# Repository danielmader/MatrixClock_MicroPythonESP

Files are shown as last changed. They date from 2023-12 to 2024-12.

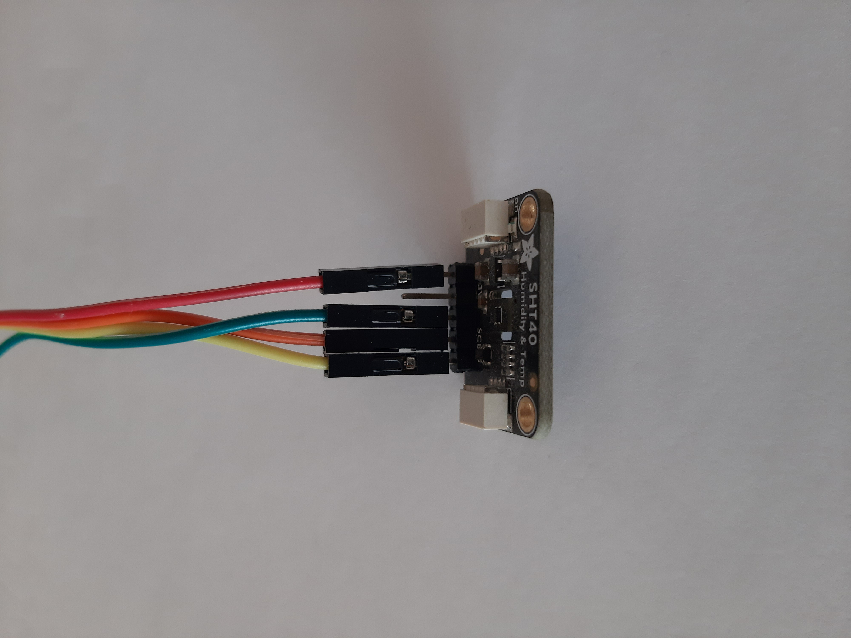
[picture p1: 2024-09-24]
20240922_105024.jpg

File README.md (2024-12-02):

# MatrixClock_MicropythonESP
A simple clock for a 64x32 HUB75 LED matrix display with scheduled NTP sync and Sensirion SHT40 ambient sensor.

# Setup

## RGB LED matrix 64x32
The display (23,95€) is from WaveShare (and was much cheaper than the similar product from Adafruit):
- https://www.waveshare.com/wiki/RGB-Matrix-P4-64x32
- https://eckstein-shop.de/WaveShare-RGB-Full-Color-LED-Matrix-Panel-64x32-Pixels-4mm-Pitch-Adjustable-Brightness

Here I've found very valuable information about how to use this kind of display:
- https://www.bigmessowires.com/2018/05/24/64-x-32-led-matrix-programming/
- https://www.sparkfun.com/news/2650

## Power supply
Interestingly enough, the display can be used without power supply, i.e. the small current fed into the HUB75 connector is enough to have the red pixels light up dimly, which is perfect for my use case as a night clock. During daytime, I'll turn on the 5V DC supply using a relay (yet to be implemented).

I'm using a salvaged 12V 1.5A power supply for the HUB75 controller. The required 5V are generated by this handy little DC-DC step-down converter (3.50€) with 10W output (15W max):
- https://eckstein-shop.de/LM2596SDC-DCeinstellbarerStep-DownSpannungsreglermitLED-VoltmeterAdjustablePowerModul

## I²C temperature and pressure sensor
The sensor (7.95€) came on a convenient break-out board from Adafruit:
- https://learn.adafruit.com/adafruit-sht40-temperature-humidity-sensor
- https://eckstein-shop.de/AdafruitSensirionSHT40Temperature26HumiditySensor-STEMMAQT2FQwiic

# Dependencies

This project requires [Ben Emmett's Hub75MicroPython](https://github.com/benjohnemmett/Hub75MicroPython) library, which is perfectly suitable for a simple MicroPython-only application. Ben was very helpful to optimize his library to maximum performance and provided numerous tips and tricks on how to implement it.

There is still a noticable flicker when the screen objects are changed (and also sporadically when the board is busy), but it is certainly acceptable for an update of the clockface every minute.

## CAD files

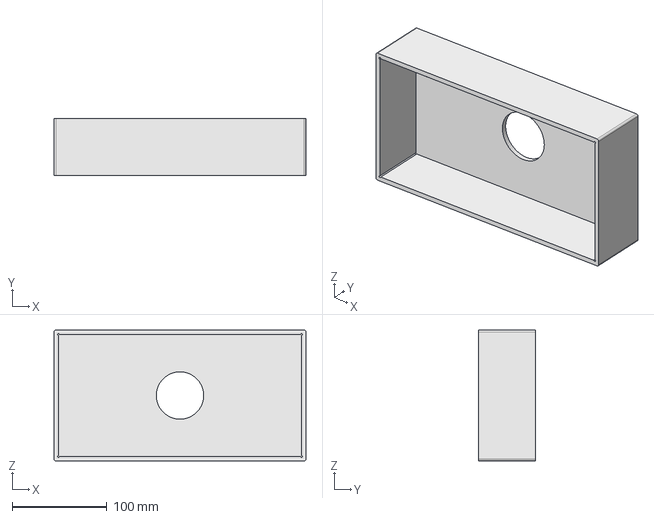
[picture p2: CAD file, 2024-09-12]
CAD/Housing v1.0.FCStd
266.0 x 60.0 x 138.0 mm

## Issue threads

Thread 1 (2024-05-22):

How to display string content?

mrhanCH, 2024-05-22:
Hello, great job. I noticed in your presentation that the red time doesn't seem very clear. Is it due to insufficient brightness? Or is it due to camera shooting?
Also, may I ask if you have a suitable method for displaying English words or Chinese characters?
Thank you!

danielmader, 2024-05-26:
Thanks for your comment!
There is no way to write letters directly with the low level approach of my project.
Maybe the Hub75 library of Circuit Python can help you.
Best luck!

Closed 2024-05-26.

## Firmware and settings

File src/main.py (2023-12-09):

# -*- coding: utf-8 -*-

"""
MatrixClock - an ESP32 driven HUB75 LED matrix clock.
* Synchronization with NTP.
* Temperature/humidity ambient sensor (Sensirion SHT40).

@author: mada
@version: 2023-12-09
"""

## System modules
from machine import Timer
from machine import Pin
from machine import I2C

import ntptime

import uasyncio as asyncio
import utime as time

## 3rd party modules
import hub75
import matrixdata
from logo import logo

## Custom modules
import wlan_util  # => creds.py
import datetime_util
import characters

##*****************************************************************************
##*****************************************************************************

## DEBUG mode -----------------------------------------------------------------
debug_mode = False
# debug_mode = True

## NTP sync interval ----------------------------------------------------------
ntp_interval = 3600 * 12  # 3600s = 60min = 1h
ts_ntpsync = 0

## Init clock -----------------------------------------------------------------
if debug_mode:
    ## Start at 05:59:00 UTC = 06:59:00 CET ...
    ts_clocktick = 60 * 60 * 5 + 59 * 60
else:
    ## Start at 00:00:00 UTC
    ts_clocktick = time.time()

## HUB75 LED matrix with custom pinout ----------------------------------------
config = hub75.Hub75SpiConfiguration()
## Row select pins
config.line_select_a_pin_number = 15
config.line_select_b_pin_number = 2
config.line_select_c_pin_number = 4
config.line_select_d_pin_number = 16
config.line_select_e_pin_number = 12
## Color data pins
config.red1_pin_number = 32
config.green1_pin_number = 33
config.blue1_pin_number = 25
config.red2_pin_number = 26
config.green2_pin_number = 27
config.blue2_pin_number = 14
## Logic pins
config.clock_pin_number = 18
config.latch_pin_number = 5
config.output_enable_pin_number = 17  # active low
config.spi_miso_pin_number = 13  # not connected
## Misc
# config.illumination_time_microseconds = 1

matrix = matrixdata.MatrixData(row_size=32, col_size=64)
matrix.record_dirty_bytes = True

hub75spi = hub75.Hub75Spi(matrix, config)

## Dot matrix characters ------------------------------------------------------
## Characters are 2D arrays with 0..7 for 3-bit colors RGB
## Blue is #001b, i.e. 1
big_blue = {
    '0' : characters.big0,         # 8 x14
    '1' : characters.big1,         # 8 x14
    '2' : characters.big2,         # 8 x14
    '3' : characters.big3,         # 8 x14
    '4' : characters.big4,         # 8 x14
    '5' : characters.big5,         # 8 x14
    '6' : characters.big6,         # 8 x14
    '7' : characters.big7,         # 8 x14
    '8' : characters.big8,         # 8 x14
    '9' : characters.big9,         # 8 x14
    '.' : characters.big_dot,      # 2 x14
    ':' : characters.big_colon,    # 2 x14
    '°' : characters.big_degree,   # 4 x14
    'C' : characters.big_degreeC,  # 8 x14
    '%' : characters.big_percent,  # 8 x14
    '-' : characters.big_dash,     # 8 x14
    ' ' : characters.big_space,    # 8 x14
    '~' : characters.pixel_black,  # 1 x1
    }

small_blue = {
    '0' : characters.small0,         # 5 x7
    '1' : characters.small1,         # 5 x7
    '2' : characters.small2,         # 5 x7
    '3' : characters.small3,         # 5 x7
    '4' : characters.small4,         # 5 x7
    '5' : characters.small5,         # 5 x7
    '6' : characters.small6,         # 5 x7
    '7' : characters.small7,         # 5 x7
    '8' : characters.small8,         # 5 x7
    '9' : characters.small9,         # 5 x7
    '.' : characters.small_dot,      # 1 x7
    ':' : characters.small_colon,    # 1 x7
    '°' : characters.small_degree,   # 3 x7
    'C' : characters.small_degreeC,  # 6 x7
    '%' : characters.small_percent,  # 5 x7
    '-' : characters.small_dash,     # 4 x7
    ' ' : characters.small_space,    # 5 x7
    '~' : characters.pixel_black,    # 1 x1
    }

## Yellow is #110b, i.e. 6
big_yellow = {}
for char in big_blue:
    big_yellow[char] = []
    for i, row in enumerate(big_blue[char]):
        row = [col * 6 for col in row]  # yellow
        big_yellow[char].append(row)
small_yellow = {}
for char in small_blue:
    small_yellow[char] = []
    for i, row in enumerate(small_blue[char]):
        row = [col * 6 for col in row]  # yellow
        small_yellow[char].append(row)

## SHT40 temperature & pressure sensor ----------------------------------------
modes = (
    ("SERIAL_NUMBER", 0x89, "Serial number", 0.01),
    ("NOHEAT_HIGHPRECISION", 0xFD, "No heater, high precision", 0.01),
    ("NOHEAT_MEDPRECISION", 0xF6, "No heater, med precision", 0.005),
    ("NOHEAT_LOWPRECISION", 0xE0, "No heater, low precision", 0.002),
    ("HIGHHEAT_1S", 0x39, "High heat, 1 second", 1.1),
    ("HIGHHEAT_100MS", 0x32, "High heat, 0.1 second", 0.11),
    ("MEDHEAT_1S", 0x2F, "Med heat, 1 second", 1.1),
    ("MEDHEAT_100MS", 0x24, "Med heat, 0.1 second", 0.11),
    ("LOWHEAT_1S", 0x1E, "Low heat, 1 second", 1.1),
    ("LOWHEAT_100MS", 0x15, "Low heat, 0.1 second", 0.11),
    )
i2c = I2C(0, scl=Pin(22), sda=Pin(21))
i2c_devs = i2c.scan()
print("\n>> found I2C devices:", i2c_devs)
sht40 = i2c_devs[0]

##*****************************************************************************
##*****************************************************************************


##=============================================================================
def read_sensor():
    '''
    Read measurement data from Sensirion SHT40.

    Returns
    -------
    * t_degC : float
    * rh_pRH : float
    '''
    # print ("\n>> reading sensor data ...")
    mode =  modes[1]  # NOHEAT_HIGHPRECISION
    i2c.writeto(sht40, bytearray([mode[1]]))
    time.sleep(mode[-1])
    rx_bytes = i2c.readfrom(sht40, 6)
    # print('>', rx_bytes, len(rx_bytes))
    t_ticks = rx_bytes[0] * 256 + rx_bytes[1]
    rh_ticks = rx_bytes[3] * 256 + rx_bytes[4]
    t_degC = -45 + 175 * t_ticks / 65535  # 2^16 - 1 = 65535
    rh_pRH = -6 + 125 * rh_ticks / 65535
    if (rh_pRH > 100):
        rh_pRH = 100
    if (rh_pRH < 0):
        rh_pRH = 0
    # print('> temperature:', t_degC)
    # print('> humidity:', rh_pRH)
    return t_degC, rh_pRH


##=============================================================================
def set_clock(timestamp=None):
    '''
    Update the display readings.
    '''
    ##-------------------------------------------------------------------------
    ## Assemble raw time and sensor strings
    if not timestamp:
        timestamp = ts_clocktick

    localtime = datetime_util.cettime(timestamp)
    # if len(localtime) == 8:
    #     ## MicroPython
    #     year, month, mday, hour, minute, second, weekday, yearday = localtime
    # elif len(localtime) == 9:
    #     ## CPython
    #     year, month, mday, hour, minute, second, weekday, yearday, dst = localtime
    hour, minute, second = localtime[3:6]
    try:
        temp, hum = read_sensor()
    except Exception:
        temp, hum = None, None

    ## DEBUG
    # if second // 10 == 0:
    #     temp, hum = 9.9, 55.5
    # elif second // 10 == 1:
    #     temp, hum = -9.9, 55.5
    # elif second // 10 == 2:
    #     temp, hum = -11.1, 55.5
    # elif second // 10 == 3:
    #     temp, hum = 3.3, 4.4
    # elif second // 10 == 4:
    #     temp, hum = 22.2, 55.5
    # elif second // 10 == 5:
    #     temp, hum = None, None

    time_str = "{:02d}:{:02d}.{:02d}".format(hour, minute, second)
    try:
        sensor_str = "{:4.1f}C {:4.1f}%".format(temp, hum)
    except ValueError:
        sensor_str = '----  ----'
    print("{} / {}".format(time_str, sensor_str))

    ##-------------------------------------------------------------------------
    ## Use darkmode during night time
    ## TODO: handle darkmode
    # if hour in [20,21,22,23,0,1,2,3,4,5,6]:
    #     darkmode = True
    # else:
    #     darkmode = False
    big = big_yellow
    small = small_yellow

    ##-------------------------------------------------------------------------
    ## Assemble character images lists per line
    time_display = []
    sensor_display = []
    ## Time HH:MM in big chars
    for char in time_str[:-3]:
        time_display.append(big[char])
    ## Time .SS in small chars
    for char in time_str[-3:]:
        time_display.append(small[char])
    ## Sensor data in small chars
    for char in sensor_str:
        sensor_display.append(small[char])

    ##-------------------------------------------------------------------------
    ## Concatenate character arrays and center on screen
    matrix.clear_dirty_bytes()
    # matrix.clear_all_bytes()

    ## Default character spacings
    space_big = 2    # default spacing for 'big'
    space_small = 1  # default spacing for 'small'

    ## 1) pixels(HH:MM)    = 2*8(+4) + 2(+2) + 2*8(+2) = 42
    ## 2) pixels(HH:MM.SS) = 42(+2) + 1+2*5(+2)        = 57
    # => 1st column index is ((64 - pixels) / 2) =
    ## 1) : 11
    ## 2) :  3.5
    ## TODO: Show full timestamp when flickerfree, see async def _set_clock()
    col = 4   # HH:MM.ss
    col = 11  # HH:MM
    for img in time_display[:-3]:
        matrix.set_pixels(5, col, img)
        col += len(img[0]) + space_big
    # for img in time_display[-3:]:
    #     matrix.set_pixels(5, col, img)
    #     col += len(img[0]) + space_small

    ## 1) pixels('xx.xC xx.x%') = 5+5+1+5+6(+5) + [5](+1) + 5+5+1+5+5(+4) = 58
    ## 2) pixels('-x.xC xx.x%') = 4+5+1+5+6(+5) + [5](+1) + 5+5+1+5+5(+4) = 57
    ## 3) pixels('-xx.xC xx.x%') = 4(+1) + 58                             = 63
    ## 4) pixels('----  ----') = 8*4 + 2*5 (+9)                           = 51
    ## => 1st column index is ((64 - pixels) / 2) =
    ## 1) :  3
    ## 2) :  3.5
    ## 3) :  0.5
    ## 4) :  6.5
    if len(sensor_str) == 11 and temp >= 0:
        col = 3
    if len(sensor_str) == 11 and temp < 0:
        col = 4
    elif len(sensor_str) == 12:
        col = 1
    elif len(sensor_str) == 10:
        col = 7
    for img in sensor_display:
        matrix.set_pixels(22, col, img)
        col += len(img[0]) + space_small


##-----------------------------------------------------------------------------
async def _set_clock(lock):
    '''
    Scheduler to update the display readings.
    '''
    while True:
        print("{:02d}.{:02d}:{:02d}".format(*time.localtime(ts_clocktick)[3:6]))

        ## TODO: update every second when when flickerfree
        # if ts_clocktick % 30 == 0:  # 2023-06-30: update every 30secs
        if ts_clocktick % 10 == 0:  # 2023-12-06: update every 10secs
            await lock.acquire()
            set_clock()
            lock.release()
        await asyncio.sleep(1)


##=============================================================================
def sync_time_NTP():
    '''
    Synchronize via NTP.
    '''
    try:
        print('\n>> syncing with NTP ...')
        ## check connection status, and (re-)connect if required
        wlan_util.connect()

        ## get time
        # print('<< NTP timestamp:', ntptime.time())
        ## set time
        ntptime.settime()
        print('<< NTP timestamp:', time.time())
        return True

    except Exception:
        print('!! NTP synchronization failed!')
        return False


##-----------------------------------------------------------------------------
async def _sync_time_NTP(lock):
    '''
    Scheduler to synchronize via NTP.
    '''
    global ts_clocktick
    global ts_ntpsync

    while True:
        if (ts_ntpsync == 0) or (ts_clocktick - ts_ntpsync > ntp_interval):
            await lock.acquire()
            for _ in range(5):
                if sync_time_NTP():
                    ts_clocktick = time.time()
                    ts_ntpsync = ts_clocktick
                    #print(datetime_util.cettime(ts_clocktick))

                    ## update clock immediately after NTP sync
                    set_clock()
                    break
            lock.release()

        await asyncio.sleep(5)


##-----------------------------------------------------------------------------
async def _refresh_display(lock):
    '''
    Scheduler to show/refresh the display.
    '''
    while True:
        await lock.acquire()
        hub75spi.display_data()
        lock.release()
        await asyncio.sleep(0)


##-----------------------------------------------------------------------------
def _clocktick(timer):
    '''
    Timed function to add one second.
    '''
    global ts_clocktick

    ts_clocktick += 1


##=============================================================================
async def main():
    ##-------------------------------------------------------------------------
    ## show Python Logo
    matrix.set_pixels(0, 16, logo)
    for _ in range(100):
        hub75spi.display_data()

    ##-------------------------------------------------------------------------
    ## init WiFi
    wlan_util.init()

    ##-------------------------------------------------------------------------
    ## init timer
    ## https://docs.micropython.org/en/latest/esp8266/quickref.html#timers
    ## https://docs.micropython.org/en/latest/esp32/quickref.html#timers
    tim = Timer(0)
    if not debug_mode:
        period = 1000
    else:
        ## run 5x faster
        period = 200
    tim.init(period=period, mode=Timer.PERIODIC, callback=_clocktick)

    ##-------------------------------------------------------------------------
    ## create the Lock instance
    lock = asyncio.Lock()

    ##-------------------------------------------------------------------------
    ## create co-routines (cooperative tasks)
    asyncio.create_task(_set_clock(lock))
    asyncio.create_task(_refresh_display(lock))
    asyncio.create_task(_sync_time_NTP(lock))

    while True:
        await asyncio.sleep(0)

try:
    asyncio.run(main())
finally:
    ## clear retained state
    _ = asyncio.new_event_loop()

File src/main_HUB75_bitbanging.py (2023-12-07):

# -*- coding: utf-8 -*-

"""
Minimum example for basic control of a HUB75 LED matrix (WaveShare 64x32) w/ NodeMCU ESP32.

@author: mada
@version: 2023-02-13
"""

## system modules
import time
#from machine import I2C
from machine import Pin

##*****************************************************************************
##*****************************************************************************

print(">>>> Setting pin definitions for HUB75 connector ...")
# R1 = Pin(25, Pin.OUT)
# G1 = Pin(26, Pin.OUT)
# B1 = Pin(27, Pin.OUT)
# R2 = Pin(14, Pin.OUT)
# G2 = Pin(12, Pin.OUT)
# B2 = Pin(13, Pin.OUT)
# E = Pin(32, Pin.OUT)
# A = Pin(19, Pin.OUT)
# B = Pin(18, Pin.OUT)
# C = Pin(5,  Pin.OUT)
# D = Pin(17, Pin.OUT)
# CLK = Pin(16, Pin.OUT)
# LAT = Pin(4,  Pin.OUT)
# OE = Pin(15, Pin.OUT)
# R1 = Pin(2, Pin.OUT)
# G1 = Pin(4, Pin.OUT)
# B1 = Pin(15, Pin.OUT)
# R2 = Pin(16, Pin.OUT)
# G2 = Pin(17, Pin.OUT)
# B2 = Pin(27, Pin.OUT)
# E = Pin(12, Pin.OUT)
# A = Pin(5, Pin.OUT)
# B = Pin(18, Pin.OUT)
# C = Pin(19,  Pin.OUT)
# D = Pin(21, Pin.OUT)
# CLK = Pin(22, Pin.OUT)
# LAT = Pin(26,  Pin.OUT)
# OE = Pin(25, Pin.OUT)
R1 = Pin(32, Pin.OUT)
G1 = Pin(33, Pin.OUT)
B1 = Pin(25, Pin.OUT)
R2 = Pin(26, Pin.OUT)
G2 = Pin(27, Pin.OUT)
B2 = Pin(14, Pin.OUT)
E = Pin(12, Pin.OUT)
A = Pin(15, Pin.OUT)
B = Pin(2, Pin.OUT)
C = Pin(4,  Pin.OUT)
D = Pin(16, Pin.OUT)
CLK = Pin(18, Pin.OUT)
LAT = Pin(5,  Pin.OUT)
OE = Pin(17, Pin.OUT)


##=============================================================================
def reset():
    '''
    Initialize all pins as low; disable output.

    Returns
    -------
    None.

    '''
    print(">>>> Reset color and row select pins ...")
    R1.value(0)
    R2.value(0)
    G1.value(0)
    G2.value(0)
    B1.value(0)
    B2.value(0)
    A.value(0)
    B.value(0)
    C.value(0)
    D.value(0)
    E.value(0)
    OE.value(0)  # enable output
    #OE.value(1)  # disable output
    CLK.value(0)
    LAT.value(0)


##=============================================================================
def set_color(rgb1, rgb2):
    '''
    Define the function to update the LED matrix.

    Parameters
    ----------
    rgb1 : TYPE
        DESCRIPTION.
    rgb2 : TYPE
        DESCRIPTION.

    Returns
    -------
    None.

    '''
    R1.value(rgb1[0])
    G1.value(rgb1[1])
    B1.value(rgb1[2])
    R2.value(rgb2[0])
    G2.value(rgb2[1])
    B2.value(rgb2[2])


##-----------------------------------------------------------------------------
## 1)
'''
https://www.bigmessowires.com/2018/05/24/64-x-32-led-matrix-programming/

1. Begin with OE, CLK, and LAT low.
2. Initialize a private row counter N to 0.
3. Set R1,G1,B1 to the desired color for row N, column 0.
4. Set R2,G2,B2 to the desired color for row HEIGHT/2+N, column 0.
5. Set CLK high, then low, to shift in the color bit.
6. Repeat steps 3-5 WIDTH times for the remaining columns.
7. Set OE high to disable the LEDs.
8. Set LAT high, then low, to load the shift register contents into the LED outputs.
9. Set ABC (or ABCD) to the current row number N.
10. Set OE low to re-enable the LEDs.
11. Increment the row counter N.
12. Repeat steps 3-11 HEIGHT/2 times for the remaining rows.
'''
reset()
# while True:
for i in range(10):
    for row in range(16):
        for col in range(64):
            if i % 3 == 0:
                if col < 21:
                    set_color((1,0,0), (0,0,1))  # noqa
                elif col < 41:
                    set_color((0,1,0), (1,0,0))  # noqa
                else:
                    set_color((0,0,1), (0,1,0))  # noqa
            elif i % 3 == 1:
                if col < 21:
                    set_color((0,0,1), (0,1,0))  # noqa
                elif col < 41:
                    set_color((1,0,0), (0,0,1))  # noqa
                else:
                    set_color((0,1,0), (1,0,0))  # noqa
            elif i % 3 == 2:
                if col < 21:
                    set_color((0,1,0), (1,0,0))  # noqa
                elif col < 41:
                    set_color((0,0,1), (0,1,0))  # noqa
                else:
                    set_color((1,0,0), (0,0,1))  # noqa
            CLK.value(1)  # a) CLK hi to shift in the color bit
            CLK.value(0)  # b) CLK lo to shift in the color bit
        OE.value(1)   # c) disable output
        LAT.value(1)  # d) LAT hi to load the shift register contents into the LED output
        LAT.value(0)  # e) LAT lo to load the shift register contents into the LED output
        A.value(row % 2)
        B.value((row // 2) % 2)
        C.value((row // 4) % 2)
        D.value((row // 8) % 2)
        E.value((row // 16) % 2)
        # print('>>', row)
        # print('A', A.value())
        # print('B', B.value())
        # print('C', C.value())
        # print('D', D.value())
        # print('E', E.value())
        OE.value(0)   # f) re-enable output

        time.sleep_ms(20)
    #time.sleep(1)

##-----------------------------------------------------------------------------
## 2)
'''
(https://www.sparkfun.com/news/2650
For each row of pixels, we repeat the following cycle of steps:
1. Clock in the data for the current row one bit at a time
2. Pull the latch and output enable pins high. This enables the latch,
   allowing the row data to reach the output driver but it also disables the output
   so that no LEDs are lit while we're switching rows.
3. Switch rows by driving the appropriate row select lines.
4. Pull the latch and output enable pins low again, enabling the output and
   closing the latch so we can clock in the next row of data.
'''
colors = [
    (1,0,1), (1,1,0), (0,1,1),  # noqa
    (1,0,1), (1,1,0), (0,1,1),  # noqa
    (1,0,1), (1,1,0), (0,1,1),  # noqa
    (1,0,1), (1,1,0), (0,1,1),  # noqa
    (1,0,1), (1,1,0), (0,1,1),  # noqa
    (1,0,1), (1,1,0), (0,1,1),  # noqa
    (1,0,1), (1,1,0), (0,1,1),  # noqa
    (1,0,1), (1,1,0), (0,1,1),  # noqa
    (1,0,1), (1,1,0), (0,1,1),  # noqa
    (1,0,1), (1,1,0), (0,1,1),  # noqa
    (1,0,1), (1,1,0), (0,1,1),  # noqa
    (1,0,1), (1,1,0), (0,1,1),  # noqa
    (1,0,1), (1,1,0), (0,1,1),  # noqa
    (1,0,1), (1,1,0), (0,1,1),  # noqa
    (1,0,1), (1,1,0), (0,1,1),  # noqa
    (1,0,1), (1,1,0), (0,1,1),  # noqa
    (1,0,1), (1,1,0), (0,1,1),  # noqa
    (1,0,1), (1,1,0), (0,1,1),  # noqa
    (1,0,1), (1,1,0), (0,1,1),  # noqa
    (1,0,1), (1,1,0), (0,1,1),  # noqa
    (1,0,1), (1,1,0), (0,1,1),  # noqa
    (1,0,1)                     # noqa
    ]

colors = [(0,0,0)] * 63 + [(1,0,0)]  # noqa
colors = [(0,0,0)] * 63 + [(0,1,0)]  # noqa
colors = [(0,0,0)] * 63 + [(0,0,1)]  # noqa
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

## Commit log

2023-03-02 Add files via upload
    Avoid blue display refresh flash by using uasyncio tasks with a lock.
    Code clean-up.
    [main.py]
2023-03-06 improved upstream issues examples
    Comparison of clear methods, general flicker.
    [main_HUB75_flicker_asyncio.py]
2023-07-06 Update main.py
    Sensor data updated every 30s; changes to avoid potential lockup when sensor is not responding.
    [main.py]
2023-12-06 characters added; more examples for main
    [characters_v0.1.xlsx, characters_v0.2.xlsx, madFonts.xlsx]
2023-12-09 allow negative temperatures
2024-09-12 First housing draft
    [Housing v1.0.FCStd, characters.xlsx]
